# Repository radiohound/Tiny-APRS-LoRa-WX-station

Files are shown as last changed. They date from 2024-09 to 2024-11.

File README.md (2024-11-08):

# Tiny-APRS-LoRa-WX-station
A project for a very low power LoRa APRS weather station<br />
This project started on jan 17 2024.<br />



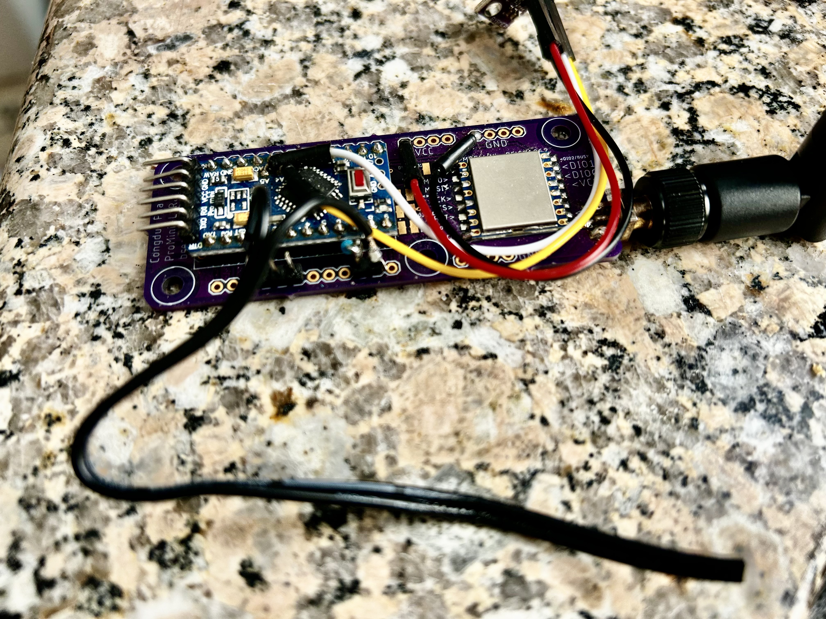
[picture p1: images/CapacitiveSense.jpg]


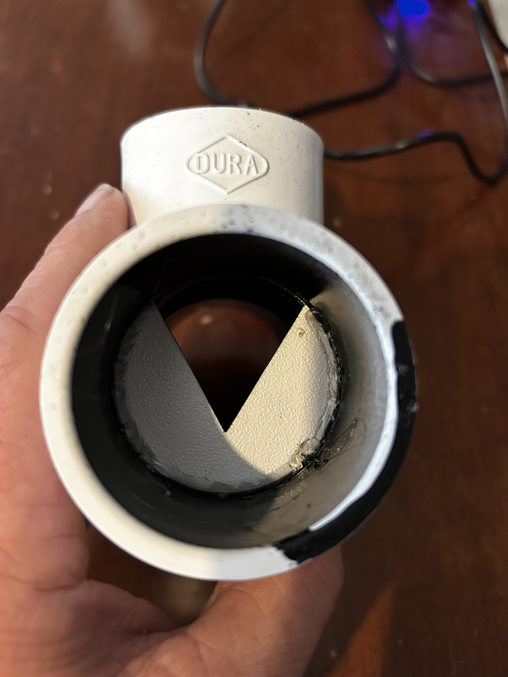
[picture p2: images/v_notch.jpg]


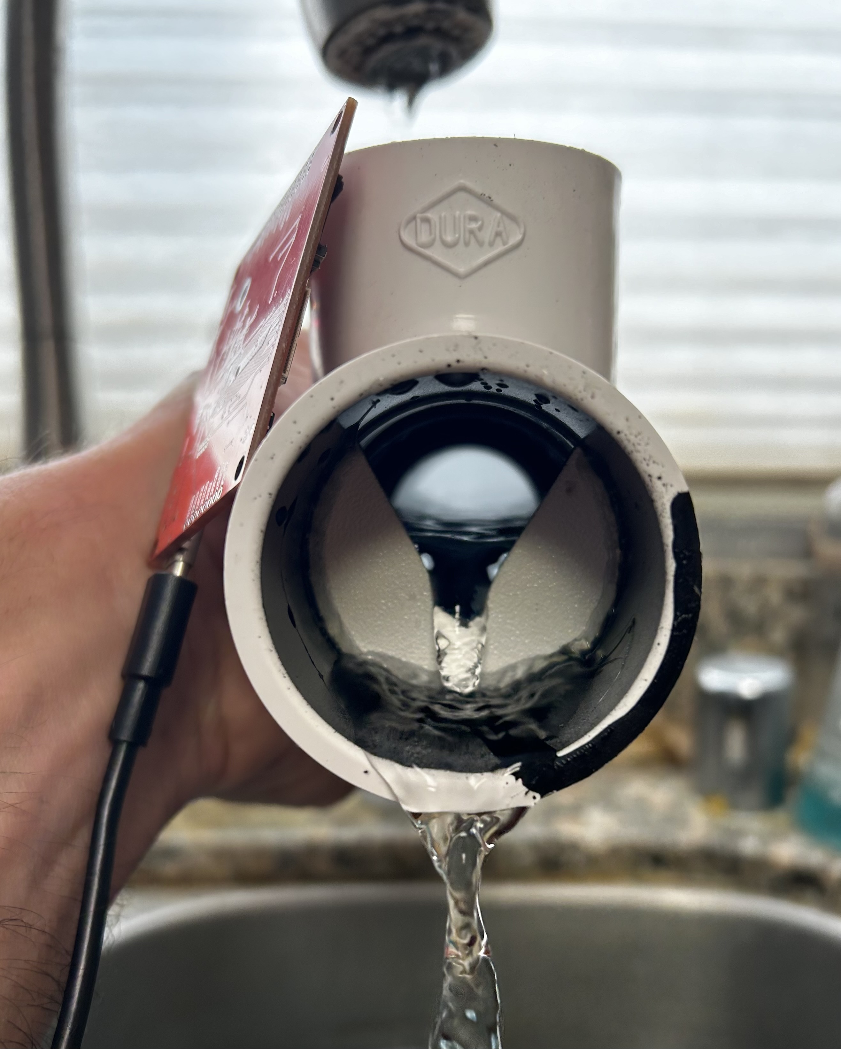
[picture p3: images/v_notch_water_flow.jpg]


Having a few Arduino Pro Mini and SX1278 RFM95W clones laying around (https://github.com/CongducPham/LowCostLoRaGw)<br />
and being more confident now that I have written my "Lora APRS WX station", I wanted to make a test with the Arduino board.<br />
I also had some PCBs ordered past year that I didn't find the time to use.<br />

It took just a few hours behind the keyboard to make a new project come to life, a "Tiny LoRa APRS WX station".<br />
It worked so well that I worked a bit more on it and finally got a nice working project!<br />

TK5EP worked to make this project VERY LOW power. Indeed does it consume only 6-7 microamperes when in sleep!!<br />

More infos on TK5EP's home page :
https://www.egloff.eu/

I get some different numbers. It may be that I have Chinese clones of the 328P on the cheap Pro Mini boards I purchased. <br />
However, the power required for db set to 8 (instead of max 20) should last for what looks like 2 years and 8 months with <br />
Energizer Ultimate lithium batteries (approx 3000mah) when allowing for outdoor temperatures. See images for measured power. <br />

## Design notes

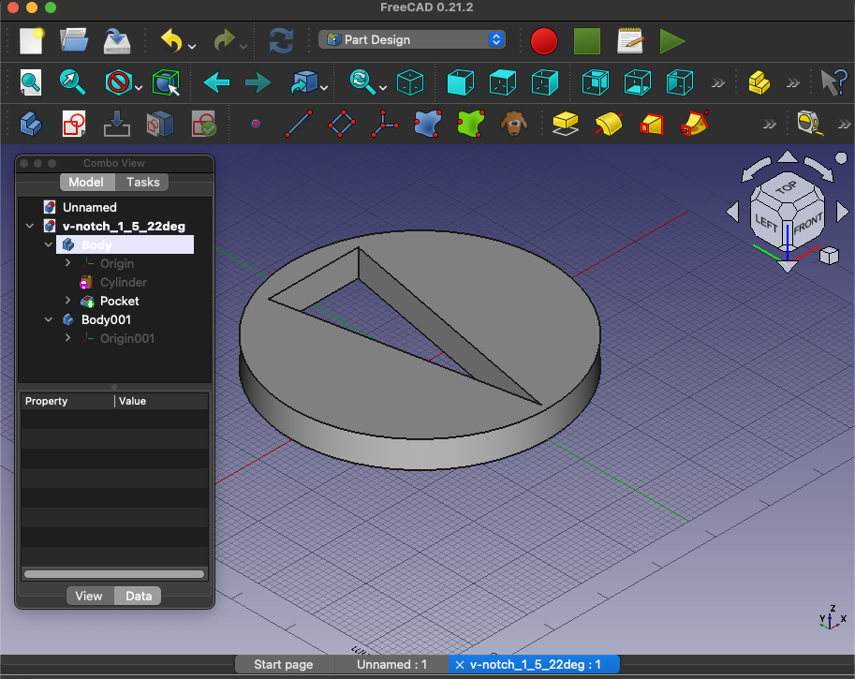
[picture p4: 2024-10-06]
images/22deg-V-notch-plate.png

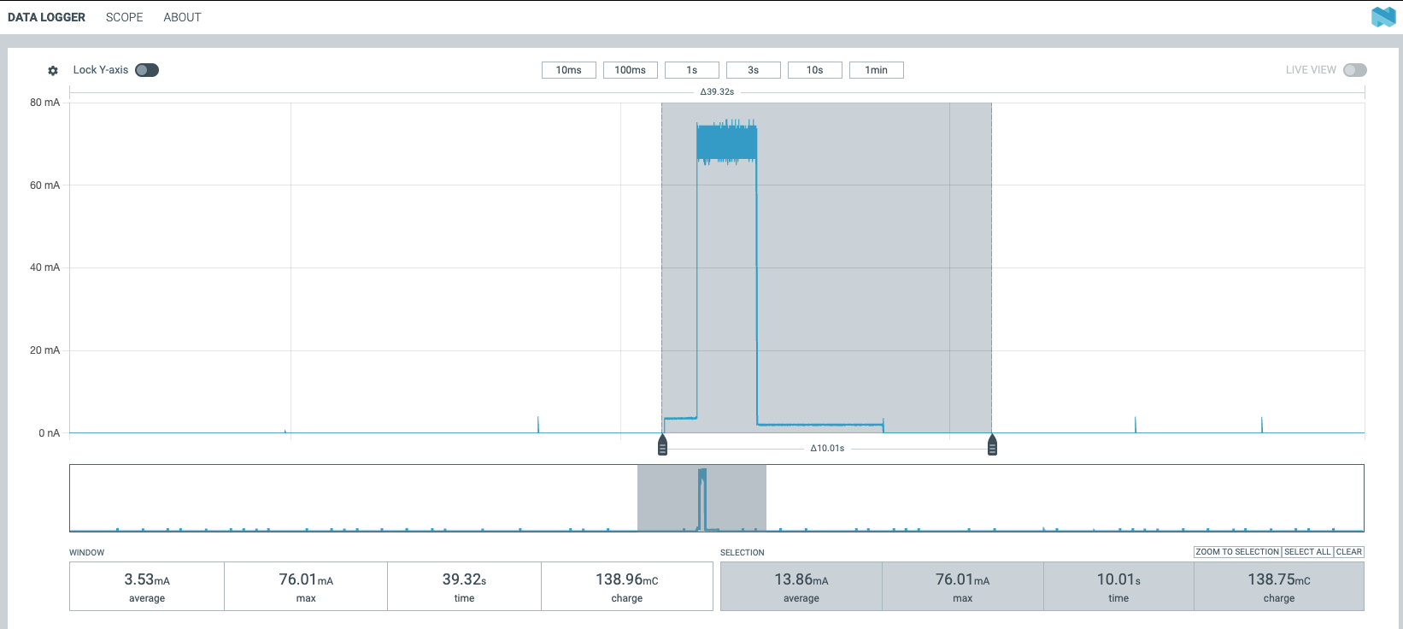
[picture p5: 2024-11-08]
images/txPower.png

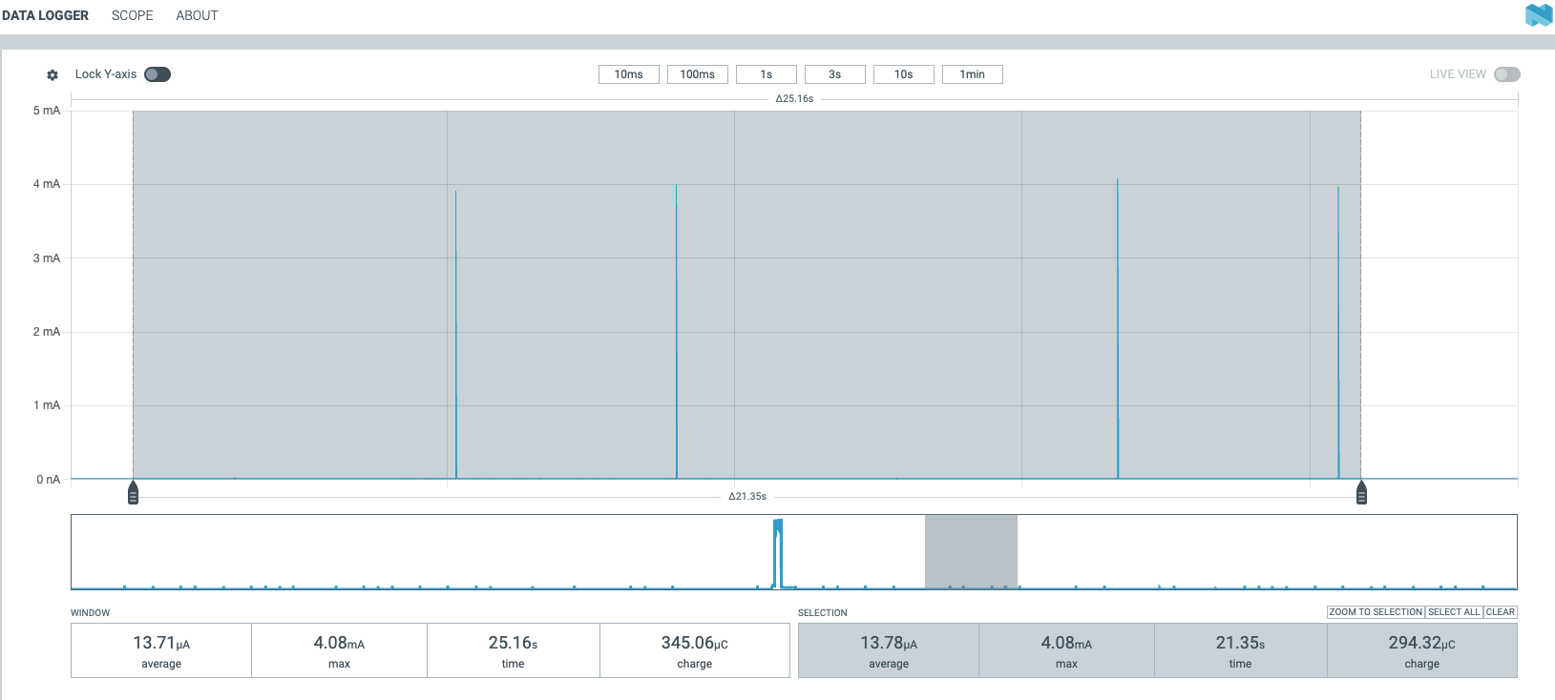
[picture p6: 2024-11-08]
images/sleepPower.png

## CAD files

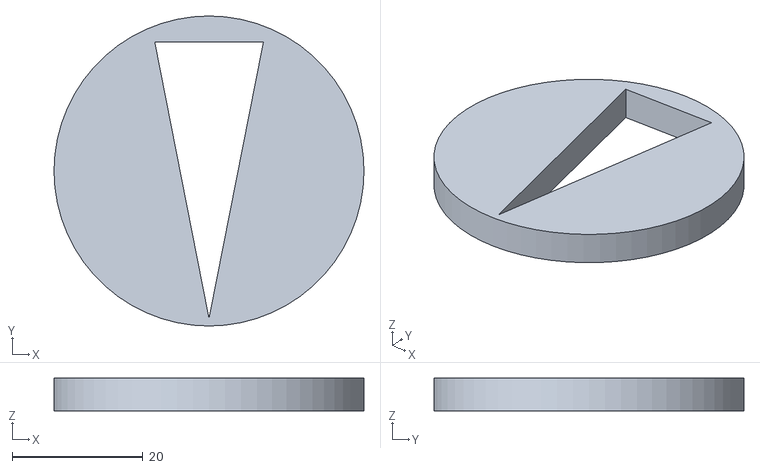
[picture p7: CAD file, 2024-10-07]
docs/v-notch_1_5_22deg-Body.stl
47.5 x 47.5 x 5.00

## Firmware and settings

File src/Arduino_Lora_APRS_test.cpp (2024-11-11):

/*
Tiny WX station
Test software for an Low power WX station LoRa with Arduino Pro mini with SX1278
2024-01-16 TK5EP

Modified by K6ATV RadioHound@gmail.com to add capacitive sensing to sense water level 
Our applicaton is to measure / detect very low flow rates from remote springs. A v-notch weir
method can be used, which causes the water to get deeper when there is higher flow. Smaller 
angles, such as around 20 degrees can be used to measure very low flow rates. See
https://www.lmnoeng.com/Weirs/vweir.php for a calculator, and 
https://www.openchannelflow.com/blog/weirs-how-low-can-you-go to get some more info, or the book
https://www.tucson.ars.ag.gov/dap/dap_docs/literature/Blue_book.pdf for way too much info.

Convert capacitance reading to Liters Per Minute using v notch weir formula for 20 degree v notch
https://www.lmnoeng.com/Weirs/vweir.php
Cubic Foot Per Second = 4.28 * C * TAN(θ/2) * (k + head)^2.5
discharge coefficient C = 0.607165052 - 0.000874466963 * θ  +  6.10393334x10-6 * θ^2 = 0.5921172861 
head correction factor k = 0.0089334615
TAN(θ/2) = TAN(20/2) = .1763
1 cubic foot per second = 28.3168 * 60 Liters per minute 
    
Liters Per Minute = 4.28 * 28.3168 * 60 * C * 0.1763 * (0.0089334615 + head)^2.5
LPM = 7272 * C * TAN(20/2) * (0.0089334615 + head)^2.5
LPM = 7272 * .592117 * .1763 * (0.0089334615 + head)^2.5
LPM = 759 * (0.0089334615 + head)^2.5
head = totalCapacitance/3243   -- This was calculated by 122 capacitance reading is equivalent to .037 feet head. 122/.037 = 3243 

Resulting formula:  LPM =  759 * pow((0.0089 + i/3243.0),2.5);

Arduino mini 3V3 8MHz and SX1278 LoRa module board from: https://github.com/CongducPham/LowCostLoRaGw
LoRa on pin D10, D4, and D2 from library: LoRa.setPins(10, 4, 2); // pins pour platine uni Pau
    * (N)SS = 10
    * RST = 4
    * DIO0 = 2
    * DIO1 = 3 - LoRa.h library does not mention this pin ... not sure why
BME280 on pin A4 SDA & A5 SCL
CapacitiveSensor using pins D7, D8 (can easily be moved, or more sensing pins added for sensing multiple locations)
This can produce water flow measurements by using v-notch weir https://www.openchannelflow.com/blog/weirs-how-low-can-you-go*/
#include <SPI.h>
#include <LoRa.h>         //https://github.com/sandeepmistry/arduino-LoRa
  // I tried using the highly ranked RadioLib library, but could not get the example to fit into the 328P chip - https://github.com/jgromes/RadioLib
#include <forcedBMX280.h> // https://github.com/soylentOrange/Forced-BMX280
#include <LowPower.h>     // https://github.com/LowPowerLab/LowPower
#include <CapacitiveSensor.h> // https://github.com/PaulStoffregen/CapacitiveSensor

#define WITH_SEALEVELCORRECTION // if we want a pressure correction for the given altitude.

const String CALLSIGN  = "K6ATV-16";  // callsign with SSID
const String STATUS    = "Sierra View Spr";
const String LATITUDE  = "3711.31N";  // APRS latitude coordinates. Go on my map to find them htpp://egloff.eu/qralocator
const String LONGITUDE = "12132.48W"; // APRS longitude coordinates
//3711.31N  Sierra View Sp
//12132.48W

//3711.43N Willow Tree Sp
//12133.01W
const int ALTITUDE     = 853;          // altitude in meters
const String CALLSIGN  = "NoCall-12";  // callsign with SSID
const String STATUS    = "put status text here";
const String LATITUDE  = "xxxx.83N";  // APRS latitude coordinates. Go on my map to find them htpp://egloff.eu/qralocator
const String LONGITUDE = "xxxxx.08W"; // APRS longitude coordinates
const int ALTITUDE     = 700;          // altitude in meters
const long TXFREQUENCY = 433775000;   // Tx frequency in Hz
const byte TXPOWER     = 20;          // in dBm, output power on the SX1278 module, max 20 dBm
const int TXPERIOD     = 1200;         // in seconds, interval between 2 transmissions

/********************************************************************
 _____              __ _                       _   _             
/  __ \            / _(_)                     | | (_)            
| /  \/ ___  _ __ | |_ _  __ _ _   _ _ __ __ _| |_ _  ___  _ __  
| |    / _ \| '_ \|  _| |/ _` | | | | '__/ _` | __| |/ _ \| '_ \ 
| \__/\ (_) | | | | | | | (_| | |_| | | | (_| | |_| | (_) | | | |
 \____/\___/|_| |_|_| |_|\__, |\__,_|_|  \__,_|\__|_|\___/|_| |_|
                          __/ |                                  
                         |___/                                   
********************************************************************/
float temperature;    // current temperature
float pressure;       // current pressure
float humidity;       // current humidity
float LPM;            // flow rate in LPM
int tempAPRS  = 0;
int humiAPRS  = 0;
int pressAPRS = 0;
char buffer[15];
float batteryvoltage = 0;
byte counter=0;
String packet ="";
String status ="";
long totalCapacitance; // current capacitance 

// init object for BME280
ForcedBME280Float climateSensor = ForcedBME280Float();
// init object for arduino capacitive sensing - only one high ohm resistor required to sense capacitance from arduino - set resistor from pin 7 to pin 8
CapacitiveSensor   cs_7_8 = CapacitiveSensor(7,8);        // 10M resistor between pins 7 & 8, pin 8 is sensor pin, add a wire and or foil/
/*******************************
 _____                 _   _                 
|  ___|   _ _ __   ___| |_(_) ___  _ __  ___ 
| |_ | | | | '_ \ / __| __| |/ _ \| '_ \/ __|
|  _|| |_| | | | | (__| |_| | (_) | | | \__ \
|_|   \__,_|_| |_|\___|\__|_|\___/|_| |_|___/ 

*******************************/

/************************************************************************
 *   Calculates the pressure at sea level (in hPa) from the specified
 *   @param  altitude      Altitude in meters
 *   @param  p0            Measured atmospheric pressure in hPa
 *   @returns              the pressure at sea level (in hPa) from the specified altitude
 *************************************************************************/
float seaLevelForAltitude(float altitude, float p0) {
  return p0 / pow(1.0 - (altitude / 44330.0), 5.255);
}

/************************************************************************
 *   Reads the BME280 sensor and converts to APRS compatible values
 *************************************************************************/
void readBME() {
    climateSensor.takeForcedMeasurement();
      temperature = climateSensor.getTemperatureCelsiusAsFloat(true);
      pressure    = climateSensor.getPressureAsFloat();
      humidity    = climateSensor.getRelativeHumidityAsFloat();
      /*
      Serial.print("Temperature: ");
      Serial.print(temperature);
      Serial.println(" °C");
      Serial.print("Humidity : ");
      Serial.print(humidity);
      Serial.println(" %");
      Serial.print("Pressure: ");
      Serial.print(pressure);
      Serial.println(" hPa");
      */
      #ifdef WITH_SEALEVELCORRECTION
          pressure = seaLevelForAltitude(ALTITUDE, pressure);
      #endif
      tempAPRS  = int((temperature * 1.8) + 32);
      humiAPRS  = int(round(humidity));
      pressAPRS = int(pressure * 10);
}

/************************************************************************
 *   Builds the WX Packet content
 *************************************************************************/  
String buildPacket(){
      sprintf(buffer, "t%03dh%02db%05d",
                        tempAPRS,
                        humiAPRS,
                        pressAPRS
                        );
      String packet = CALLSIGN + ">APEP02,WIDE1-1:!" + LATITUDE + "/" + LONGITUDE + "_.../...g..." + buffer + "(Bat=" + batteryvoltage + "V, LPM=" + LPM + ")";
      return packet;
}

/************************************************************************
 *   Builds the Status packet - But this is only sent during at startup, conserving battery power for WX Packet only
 *************************************************************************/
String buildStatus(){
  String datas = CALLSIGN + ">APEP02,WIDE1-1:>" + STATUS;
  return datas;
}

/************************************************************************
 *   Sends the WX Packet over LoRa RF
************************************************************************/
void sendPacket(String packet) {
      while (LoRa.beginPacket() == 0) {
        Serial.print("waiting for radio ... ");
        delay(100);
      }
      Serial.print("Sending packet: ");

      // send packet
      LoRa.beginPacket();
      LoRa.write('<');
      LoRa.write(0xFF);
      LoRa.write(0x01);
      
      //Serial.println(packet);
      //String newPacket = "TK5EP-12>APWXEP,WIDE1-1:>WX station by TK5EP";
      LoRa.write((const uint8_t *)packet.c_str(), packet.length());
      LoRa.endPacket();
}

/************************************************************************
*   Measures the supply voltage of Arduino. Doesn't need any external hardware
*************************************************************************/
// https://forum.arduino.cc/t/can-an-arduino-measure-the-voltage-of-its-own-power-source/669954/4
long readVcc() { 
    long result;
      // Read 1.1V reference against AVcc
      ADMUX = _BV(REFS0) | _BV(MUX3) | _BV(MUX2) | _BV(MUX1);
      delay(2); // Wait for Vref to settle
      ADCSRA |= _BV(ADSC); // Convert
      while (bit_is_set(ADCSRA,ADSC));
      result = ADCL;
      result |= ADCH<<8;
      result = 1126400L / result; // Back-calculate AVcc in mV
      //Serial.print("Voltage = ");
      //Serial.print(result/1000.00);
      //Serial.println(" V");
	    //Serial.flush();
      return result;
}

/*****************************
 _____      _               
/  ___|    | |              
\ `--.  ___| |_ _   _ _ __  
 `--. \/ _ \ __| | | | '_ \ 
/\__/ /  __/ |_| |_| | |_) |
\____/ \___|\__|\__,_| .__/ 
                     | |    
                     |_|    
******************************/
void setup() {
  cs_7_8.set_CS_AutocaL_Millis(0xFFFFFFFF);     // turn off autocalibrate on channel 1 - just as an example
  Serial.begin(115200);
  while (!Serial) { 
    delay(10);
  }
  Wire.begin(); // needed for climatesensor
  // try to initiate the BME280
  while (climateSensor.begin()) {
  Serial.println("Waiting for sensor...");
  digitalWrite(LED_BUILTIN, !digitalRead(LED_BUILTIN));
  delay(1000);
  }
  // initiate the SX1278
  if (!LoRa.begin(TXFREQUENCY)) {
    Serial.println("Starting LoRa failed!");
    while (1);
  }
  Serial.println("LoRa init succeeded.");
  //LoRa.setPins(10, 4, 2); // This does not seem to be necessary
  LoRa.setSpreadingFactor(12);
  LoRa.setSignalBandwidth(125E3);
  LoRa.setCodingRate4(5);
  LoRa.enableCrc();
  LoRa.setTxPower(TXPOWER);

  
  // read the BME280 sensor
  readBME();
  // read the capacitance
  totalCapacitance =  cs_7_8.capacitiveSensor(30);
  // read the battery voltage
  batteryvoltage = readVcc()/1000.00;
  // build the APRS load
  packet = buildPacket();
  // send the datas packet
  sendPacket(packet);
  delay (5000);
  // build the APRS status load
  status = buildStatus();
  // send the status packet
  sendPacket(status);
}

/*****************************
 _                       
| |                      
| |     ___   ___  _ __  
| |    / _ \ / _ \| '_ \ 
| |___| (_) | (_) | |_) |
\_____/\___/ \___/| .__/ 
                  | |    
                  |_|    
*****************************/
void loop() {
  // put in sleep modes
  LowPower.powerDown(SLEEP_8S, ADC_OFF, BOD_OFF);
  LoRa.sleep();
  // make several loops depending of the TXPERIOD
  // we go to sleep for 8s at each loop
  ++counter;
  Serial.println(counter);
  Serial.flush();
  // if number of loops reached
  // we measure, build and transmit
  if (counter == round(TXPERIOD/8)) {
    delay(500);
    totalCapacitance =  cs_7_8.capacitiveSensor(30);
    LPM =  759 * pow((0.0089 + totalCapacitance/3243.0),2.5);
    readBME();
    batteryvoltage = readVcc()/1000.00;
    packet = buildPacket();
    sendPacket(packet);
    //Serial.println(packet);
    counter =0;
    //this does not seem to save power
    // I am seeing about 2 mA for 8 seconds after each transmission
    LowPower.powerDown(SLEEP_8S, ADC_OFF, BOD_OFF);
    LoRa.sleep();
    }
 } // end loop

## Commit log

2024-09-24 Update platformio.ini with capacitive sensor library
2024-09-24 Update Arduino_Lora_APRS_test.cpp
    Some cleanup, and editing of function descriptions. Include for CapacitiveSensor for measuring water level for future use
2024-09-24 Update Arduino_Lora_APRS_test.cpp
    Some more cleanup for description of functions
2024-09-25 Update Arduino_Lora_APRS_test.cpp
    added capacitance readings and sending in packet
2024-09-25 Update Arduino_Lora_APRS_test.cpp
    edits
2024-09-28 Update Arduino_Lora_APRS_test.cpp
    Had conflict with pin 3, which is wired to DIO1 on the LoRa chip. Capacitive write pin changed to pin 7. Now getting steady capacitance readings.
2024-09-28 Update Arduino_Lora_APRS_test.cpp
    forgot to rename the capacitive sensing pins
2024-09-28 Update Arduino_Lora_APRS_test.cpp
    added link to board design files
2024-10-06 Add files via upload
    v-notch plate for 1.5 inch PVC pipe
2024-10-07 Add files via upload
    3d model of v-notch plate for 3d printing. Fits into 1.5" pvc T
    [v-notch_1_5_22deg-Body.stl]
2024-10-21 Update README.md
    Updated power usage that I experienced
2024-10-21 Add files via upload
    added power measurement photos
2024-10-22 Update Arduino_Lora_APRS_test.cpp
    Make it easier to edit status text
2024-11-11 Added flow formula to output Liters Per Minute
